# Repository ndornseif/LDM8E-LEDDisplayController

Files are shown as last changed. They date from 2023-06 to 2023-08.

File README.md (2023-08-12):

# LDM8E-LED Display Controller
Controller to drive LDM1 or LDM2 modules. 

## Overview
The LDM8E is designed to drive a string of up to four LDM1 or LDM2 display modules.  
It allows individual segment addressing and whole display dimming.  
**Do not mix different display module types.**

## Board overview
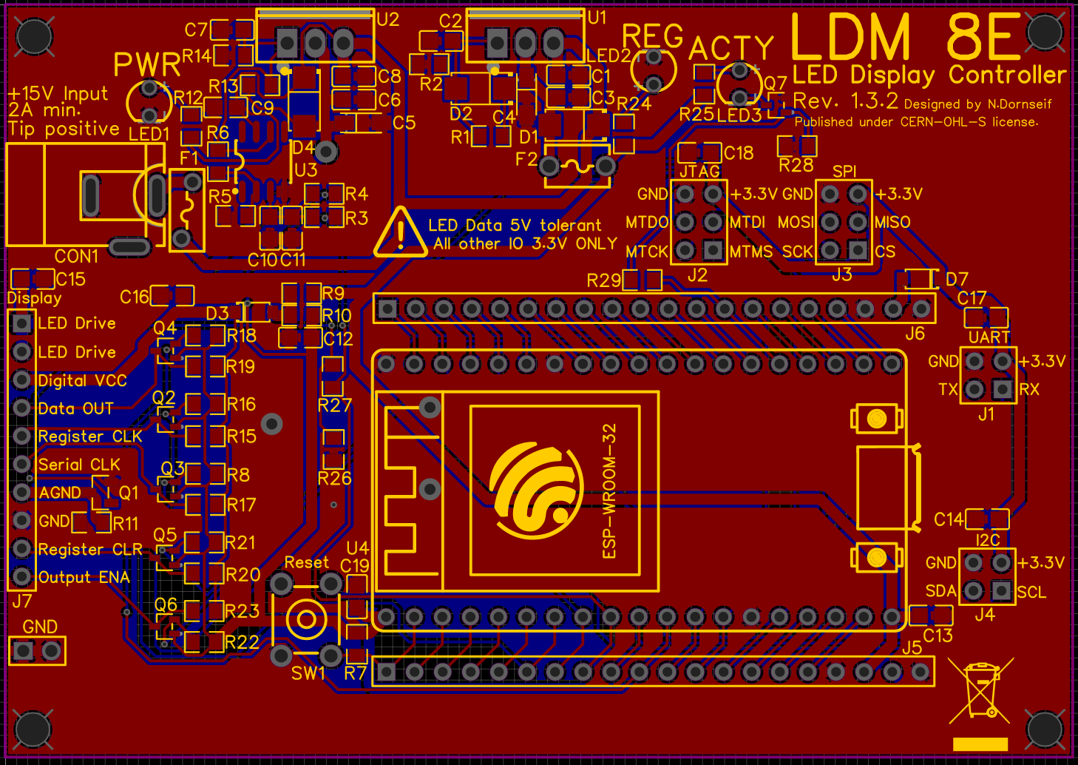
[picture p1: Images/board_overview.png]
Topside of circuit board


## Dimming
The controller supports three different dimming modes.  
Analog dimming, achieved by changing the LED driving voltage,  
Split ground PWM using a separate LED ground and  
Chip Enable PWM using the shift register enable pins.  
Different modes need different components populated.

### Analog dimming
When analog dimming, the output voltage of the driving voltage regulator (U2) is adjusted by
Omitting the feedback network and driving the regulator adjust pin from MCU DAC1 through an op amp (U3).  
Adding R11 connects the LED ground to the supply ground and turns them on constantly, allowing analog dimming.  
Populate: R3, R4, R5, R6, R11, C10, C11, U3  
Omit: Q1, R13, R14, R26, R27  

### PWM dimming  
Including the feedback network R13, R14 fixes the driving voltage regulator (U2) output voltage to 12.7V.  
The brightness is then controlled using PWM by switching the LEDs on and off rapidly. 

#### Split ground PWM dimming  
LDM1 modules use a separate LED ground that is switched using Q1 to achieve dimming.  
Populate: Q1, R13, R14, R26, R27  
Omit: R3, R4, R5, R6, R11, C10, C11, U3, C9  

#### Chip enable PWM dimming  
LDM2 modules use the shift register output enable pin to switch the LEDs.  
Populate: R11, R13, R14  
Omit: R3, R4, R5, R6, R26, R27, C10, C11, Q1, U3, C9  

## Selecting module logic voltage
The LDM8E has configurable level shifters on the LED logic pins.  
The voltage can be set using either R9 or R10. Populating R9 sets it to 5V, R10 to 3.3V.  
LDM1 modules work with both, LDM2 modules need 5V logic voltages.  

## Connectors/Headers
- Power input (CON1): +15V power supply, tip positive, min. 2A
- LED connector (J7): Connect a string of LDM1 or LDM2 modules here.  
The following connectors are strictly 3.3V only.  
- UART (J1): Connects to MCU UART pins. 
- JTAG (J2): Connects to MCU JTAG pins.
- SPI (J3): Connects to MCU SPI pins.
- I2C (J4): Connects to MCU I2C pins.
- GPIO (J5 and J6): Breakout of MCU GPIO pins and PSU voltages (see schematic for pinout).  
The 3.3V supply is generated using the MCU's onboard regulator. *Do not load unnecessarily.*  

## LED Connector pinout
- LED Drive: LED supply voltage.   
The value depends on the selected dimming mode.    
- Digital VCC: digital supply voltage. Set using R9 or R10 (R9 = 5V, R10 = 3.3V).  
- Data OUT: Serial data sent to modules.  
- Register CLK: Module output register clock.  
- Serial CLK: Serial data clock.  
- AGND: LED ground (connected to GND using Q1 or R11).  
AGND is tied to GND internally on LDM2 modules.  
- GND: Digital ground.
- Register CLR: Clear module shift registers (active low).
- Output ENA: Enable module LEDs (unused on LDM1 modules) (active low).

## Microcontroller board selection
Any ESP32 board that is pin compatible with the Node MCU should work.  
I have only tested a "AZ-Delivery ESP32 NodeMCU" board based on the ESP32-S and CH340.

## Arduino library
An Arduino library for easy use of the LDM8E can be found [here](https://github.com/ndornseif/LDM8E-Library).

## Considerations
Do not plug into the MCU's USB port while it is installed in the LDM8E; high current will be drawn from the USB 5V rail.  
With 4 modules using analog dimming, the drive voltage regulator (U2) can dissipate up to **2W!**   
**Ensure adequate cooling of both linear regulators (U1 and U2)!**  

## Other
Published under CERN-OHL-S license.

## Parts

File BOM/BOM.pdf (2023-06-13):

LDM8E-BOM

Page 1

Name | Designator | Footprint | Quantity
R 100k | R26,R28,R7 | R0805 | 3
R 100 | R27,R29 | R0805 | 2
R 2.2k | R14 | R0805 | 1
R 240 | R1, R13 | R0805 | 2
R 680 | R2 | R0805 | 1
R 1M | R3 | R0805 | 1
R 1.5M | R4 | R0805 | 1
R 10k | R5,R8,R15,R16,R17,R18,R19,R20,R21,R22,R23 | R0805 | 11
R 27k | R6 | R0805 | 1
R 0 | R9,R10,R11 | R0805 | 3
R 1.3k | R12 | R0805 | 1
R 300 | R24,R25 | R0805 | 2
C 0.1u | C1,C2,C3,C6,C7,C8,C9,C10,C11,C12,C13,C14,C15,C16,C17,C18,C19 C0805 | 17
C 10u | C4,C5 | CAP-SMD_L3.2-W1.6 | 2
3mm LED | LED1,LED2,LED3 | LED-TH_BD3.0 | 3
30R090UU Polyfuse | F1 | FUSE-TH_L7.4-W3.1-P5.10-D0.6-S1.00 | 1
60R025XPR Polyfuse | F2 | FUSE-TH_L5.8-W3.8-P5.10-D0.8 | 1
Pin Header 1x2 | GND | HDR-M-2.54_1X2 | 1
Pin Header 2x2 | J1,J4 | HDR-M-2.54_2X2 | 2
Pin Header 2x3 | J2,J3 | HDR-M-2.54_2X3 | 2
Pin Header 1x20 | J5,J6 | HDR-M-2.54_1X20 | 2
Pin Header 1x10 | J7 | HDR-M-2.54_1X10 | 1
MRA4007T3G Diode | D1,D2,D4 | SMA_L4.3-W2.6 | 3
MBR0580TP Diode | D3,D7 | SOD-123_L2.8-W1.8 | 2
PMV20ENR Mosfet | Q1 | SOT-23-3_L2.9-W1.3 | 1
LBSS138WT1G Mosfet | Q2,Q3,Q4,Q5,Q6,Q7 | SOT-323-3_L2.0-W1.3 | 6
LM317 Regulator | U1,U2 | TO-220-3_L10.0-W4.5 | 2
TLV07IDR Op-Amp | U3 | SOIC-8_L5.0-W4.0 | 1
Node MCU | U4 | - | 1
Power Jack | CON1 | DC-IN-TH_POWER-JACK | 1

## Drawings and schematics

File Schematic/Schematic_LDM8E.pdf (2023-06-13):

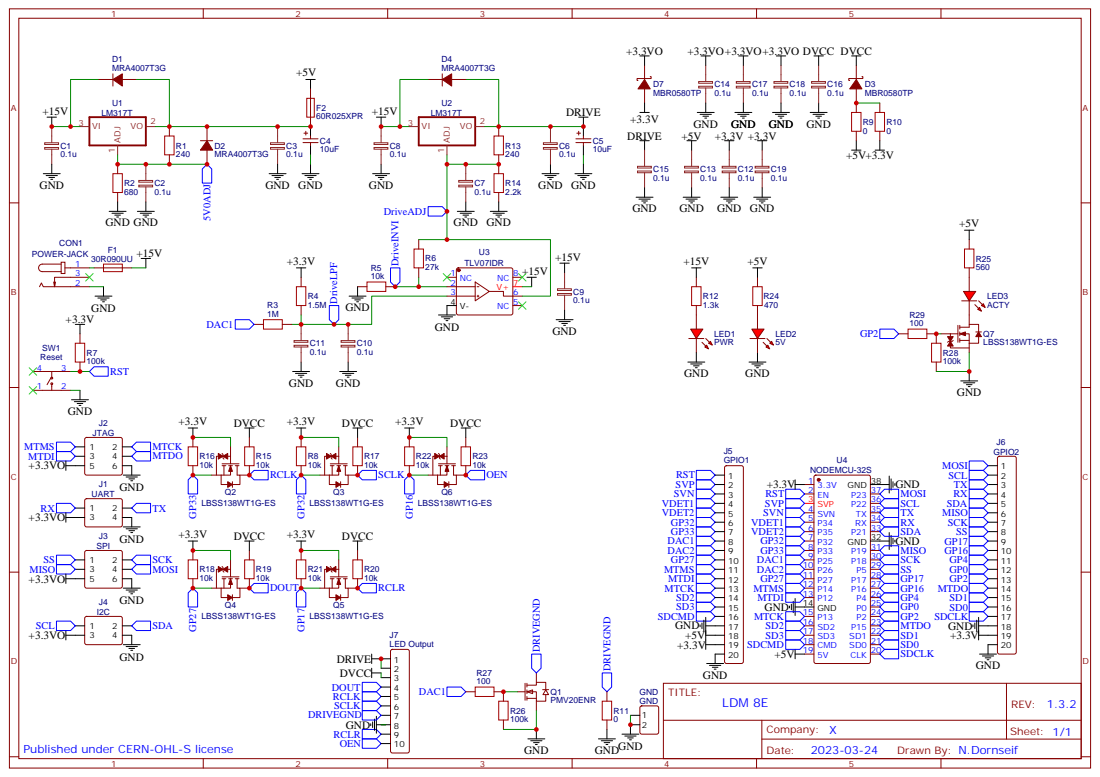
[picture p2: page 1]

Published under CERN-OHL-S license
